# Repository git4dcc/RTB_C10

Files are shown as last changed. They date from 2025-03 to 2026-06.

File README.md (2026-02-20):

# RTB_C10





My homebrew RTB C10 Bus Master connects the PC with the model railway layout via USB. The bus master is responsible for the bus timing and scales from small testing beads to large scale layouts.

<details>
<summary>See also</summary>

- [RTB_C11 - Power](/../../../../git4dcc/RTB_C11)
- [RTB_C12 - Booster](/../../../../git4dcc/RTB_C12)
- [RTB_C13 - Track Sensor](/../../../../git4dcc/RTB_C13)
- [RTB_P15 - Base](/../../../../git4dcc/RTB_P15)

</details>

<details>
<summary>User Guides</summary>

- User Guide - DE
- [User Guide - EN](https://rtb4dcc.de/rtb_user_guide_en/)

</details>

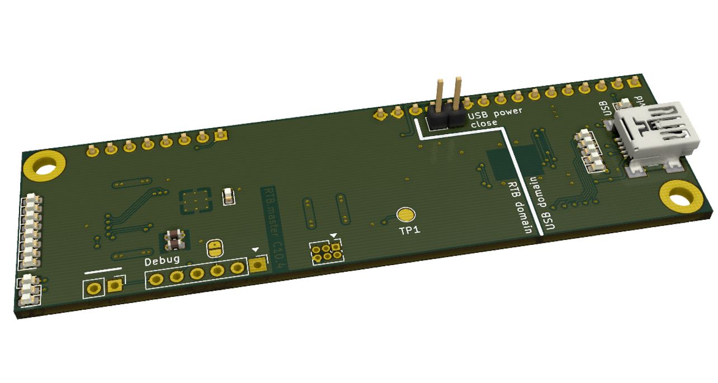
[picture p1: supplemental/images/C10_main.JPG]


## Master features
- **USB**
  - USB 2.0 (3Mbps full duplex)
  - Mini-B connector
  - easy firmware update over USB
  - galvanic isolated
- **USB Power Source**
  - can provide power to other components
  - active limited to 500mA
  - short circuit protection
- **bus master**
  - FDX bus head (2Mbps full duplex)
  - fail safe operation

# Hardware
The PCB layout uses SMD footprints with 0.4mm pitch and postly 0603 parts. Reflow soldering is recommended, but with some experience handsoldering is also possible.
Further, the PCB has been optimized for automated assembly (BOM and Position files as CSV).

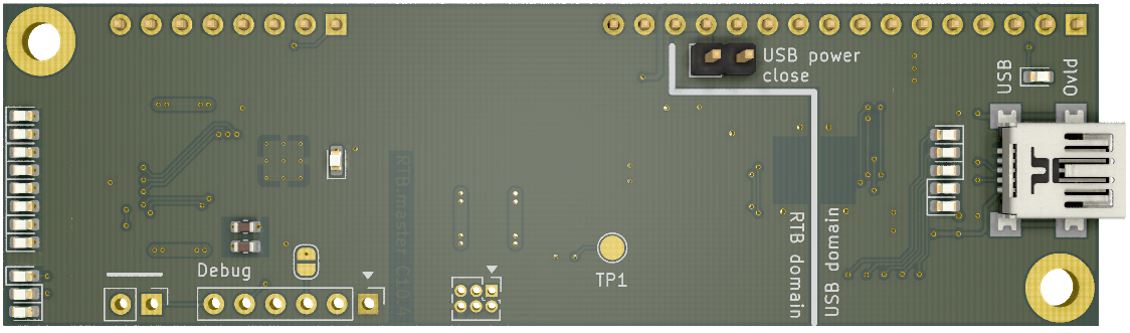
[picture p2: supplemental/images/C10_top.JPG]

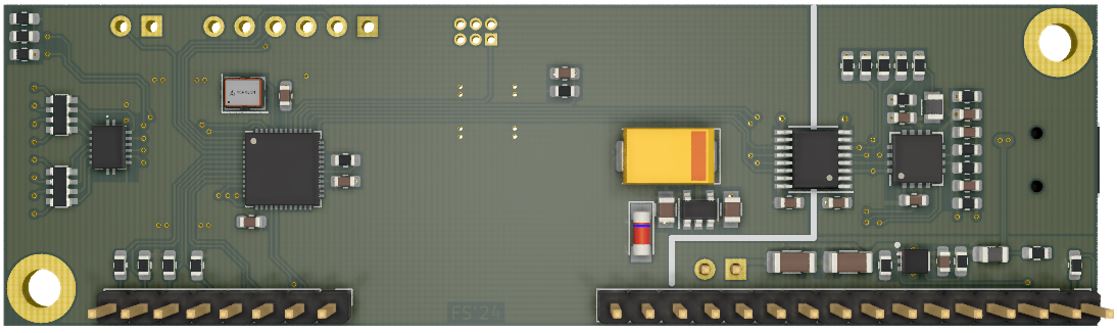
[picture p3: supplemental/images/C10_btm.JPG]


## PCB
- 2-layer PCB, FR4, 1.6mm
- CPU: AVR64DB48
- USB: FT232X (Mini-B)
- PMIC: TPS2552DRVT

## Kicad
[Schematic](doc/C10_schematic.pdf) | [Layout](doc/C10_layout.pdf) | [Gerber](gerber)

<details>
<summary>Dependency</summary>
<br>

:yellow_circle: Requires my Kicad project library [RTB_SamacSys](/../../../../git4dcc/RTB_SamacSys) in the same directory tree.

</details>

## Firmware
Filename structure: { **pcb** }{ **code** }{ **version** }.hex

Example: **C10F0001**.hex

| | Description |
| --- | --- |
| **pcb** | Name of matching hardware (**C10**) |
| **code** | Type of code contained (**R**=rom, **B**=bootloader, **F**=flash, **U**=bld update, **P**=UPDI factory code) |
| **version** | Release version (**####**) |

[Firmware files](firmware)

## UPDI / Fuses
The fuse settings as well as the P-code (C10Pxxxx.hex) has to be installed by using UPDI.<br>

| Fuses Setting |
| --- |
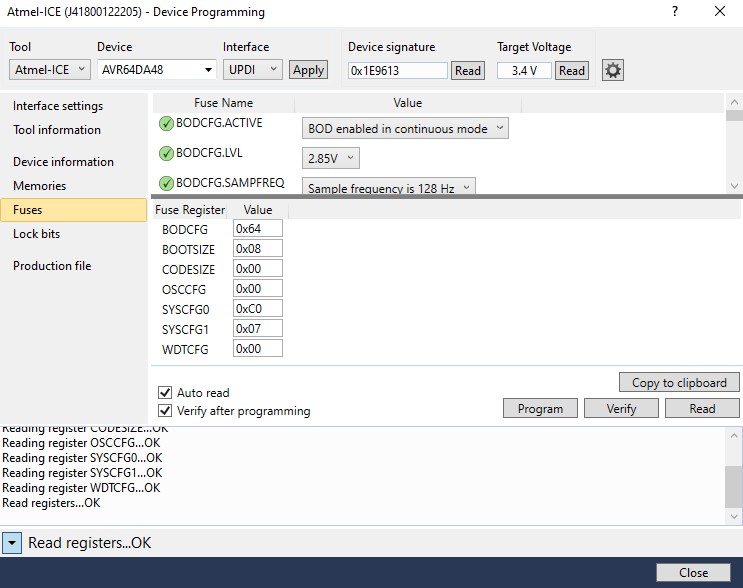
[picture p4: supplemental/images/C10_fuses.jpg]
||

# Images
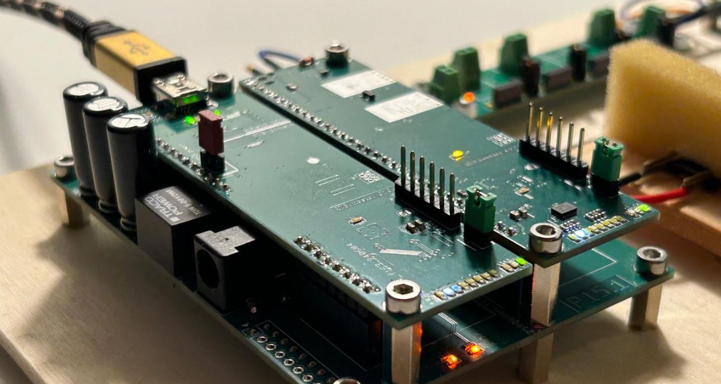
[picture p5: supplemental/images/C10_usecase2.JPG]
 

# YouTube
See the C10 bus master in action.<br><br>
[](https://youtu.be/n1b2I9GNrNY)

This project is intended for hobby use only and is distributed in accordance with the Apache License 2.0 agreement.

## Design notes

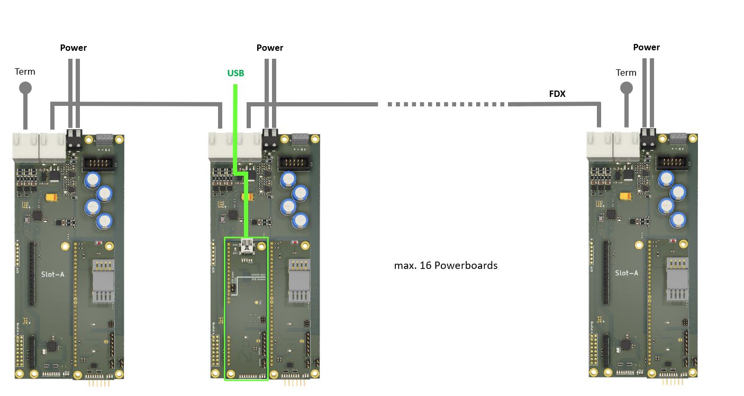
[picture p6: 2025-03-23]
supplemental/images/C10_usecase3.JPG

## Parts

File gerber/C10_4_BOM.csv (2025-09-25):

Designator | Footprint | Quantity | Value | LCSC Part #
C10, C11, C12, C13, C17, C18, C22, C4, C5, C7, C8, C9 | 0603 | 12 | 100nF | C14663
C14, C15 | 0603 | 2 | 47pF | C5137501
C16 | 1206 | 1 | 22uF/25V | C12891
C19, C20 | 1206 | 2 | 220u/6.3V | C15008
C2 | 0805 | 1 | 100nF/50V | C49678
C3 | 0805 | 1 | 10uF/25V | C5137488
C6 | 0603 | 1 | 4.7uF | C19666
D1 | D_SOD-123F | 1 | BAS16H,115 | C130413
D11, D12 | 0603 | 2 | LED(grn)
D14, D32, D33, D34, D35, D36, D37, D38 | 0603 | 8 | LED(wht) | C2290
D17 | 0603 | 1 | RTS(red)
D18 | 0603 | 1 | CTS(red)
D2 | 0603 | 1 | Locate(blue) | C434421
D3 | 0603 | 1 | Reset(red) | C2986060
D4 | 0603 | 1 | Hbt(grn) | C84264
D5 | 0603 | 1 | PWR(grn) | C84264
D6 | 0603 | 1 | Alarm(pink)
D8 | 0603 | 1 | PWR(grn)
H1, H2 | MountingHole_3.2mm_M3_ISO7380_Pad | 2 | MountingHole
IC1 | SON65P200X200X80-7N | 1 | TPS2553DRVT | C2871420
IC3 | 74HC595BQ115 | 1 | 74HC595BQ,115 | C547123
J1 | USB_Micro-B_Reichelt_BWM_SMD | 1 | USB_B_Mini
J2 | PinHeader_1x16_P2.54mm_Vertical | 1 | Conn_01x16_Male
J3 | PinHeader_1x06_P2.54mm_Vertical | 1 | Debug IF
J4 | PinHeader_2x03_P1.27mm_Vertical | 1 | UPDI
J5 | PinHeader_1x08_P2.54mm_Vertical | 1 | Conn_01x08_Male
JP1 | SolderJumper-2_P1.3mm_Open_RoundedPad1.0x1.5mm | 1 | SolderJumper_2_Open
JP2 | PinHeader_1x02_P2.54mm_Vertical | 1 | Jumper_2_Open
JP3 | PinHeader_1x02_P2.54mm_Vertical | 1 | USB power
L1, L2 | 0805 | 2 | Ferrite_Bead | C845118
R1, R12, R6, R7, R8 | 0603 | 5 | 1k | C21190
R10 | 0603 | 1 | 18k | C25810
R11, R2, R28, R4, R5 | 0603 | 5 | 3.3k | C22978
R15, R22, R23, R29, R30 | 0603 | 5 | 3.3k | 0603WAF3301T5E
R16, R20 | 0603 | 2 | 27 | C23345
R3 | 0603 | 1 | 100 | C22775
R9 | 0603 | 1 | 100k | C25803
RN3, RN4 | R_Array_Convex_4x0603 | 2 | 4.7k | C1980
TP1 | TestPoint_Pad_D2.0mm | 1 | TestPoint
U2 | UQFN-48-1EP_6x6mm_P0.4mm_EP4.45x4.45mm_ThermalVias | 1 | AVR64DA48 | C3227372
U5 | SOT-23-5 | 1 | MIC5205-3.3YM5 | C37970
U6 | QFN-16-1EP_4x4mm_P0.65mm_EP2.7x2.7mm | 1 | FT230XQ | C128629
U7 | SSOP-16_3.9x4.9mm_P0.635mm | 1 | ISO7742 | C5216468
X1 | Oscillator_SMD_Abracon_ASE-4Pin_3.2x2.5mm | 1 | ASE-24MHz | C1987527

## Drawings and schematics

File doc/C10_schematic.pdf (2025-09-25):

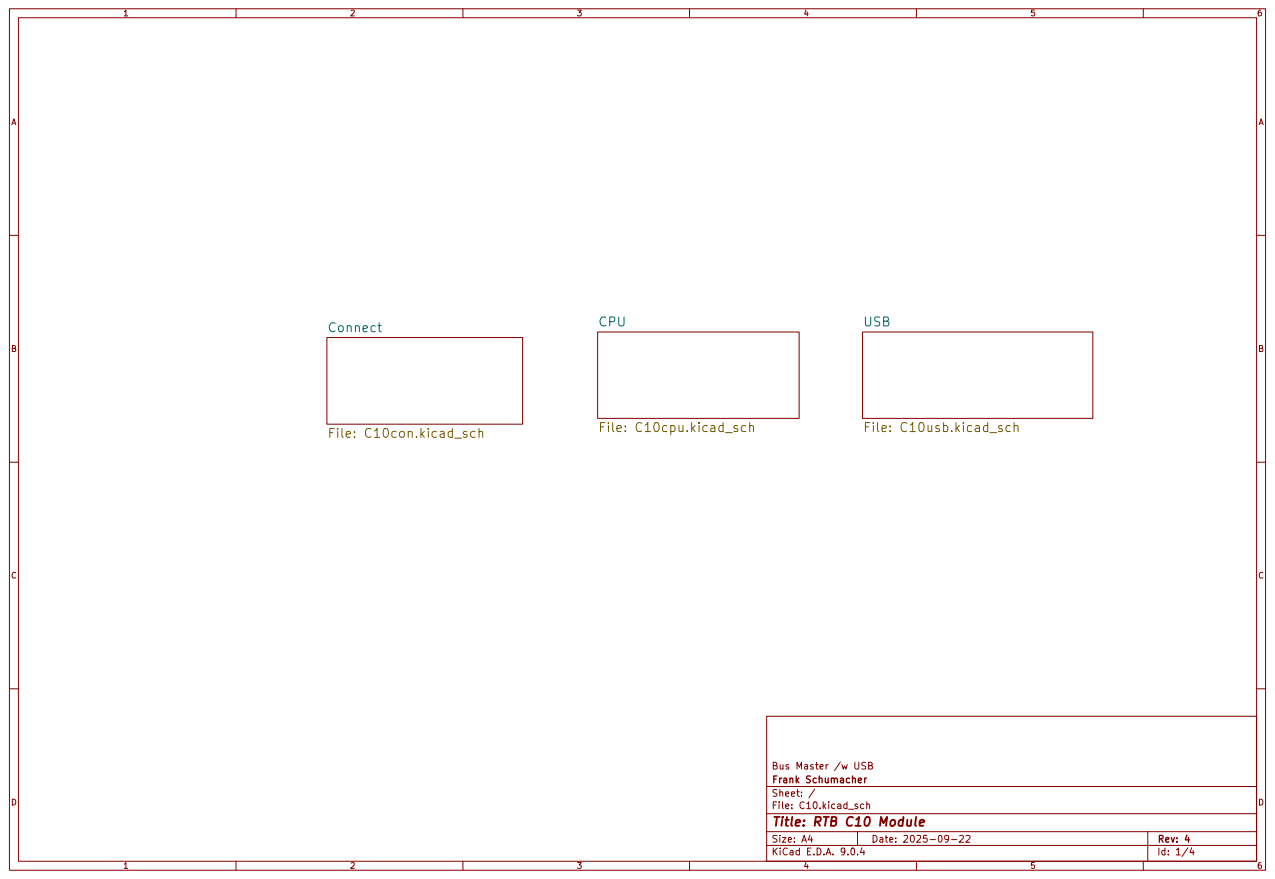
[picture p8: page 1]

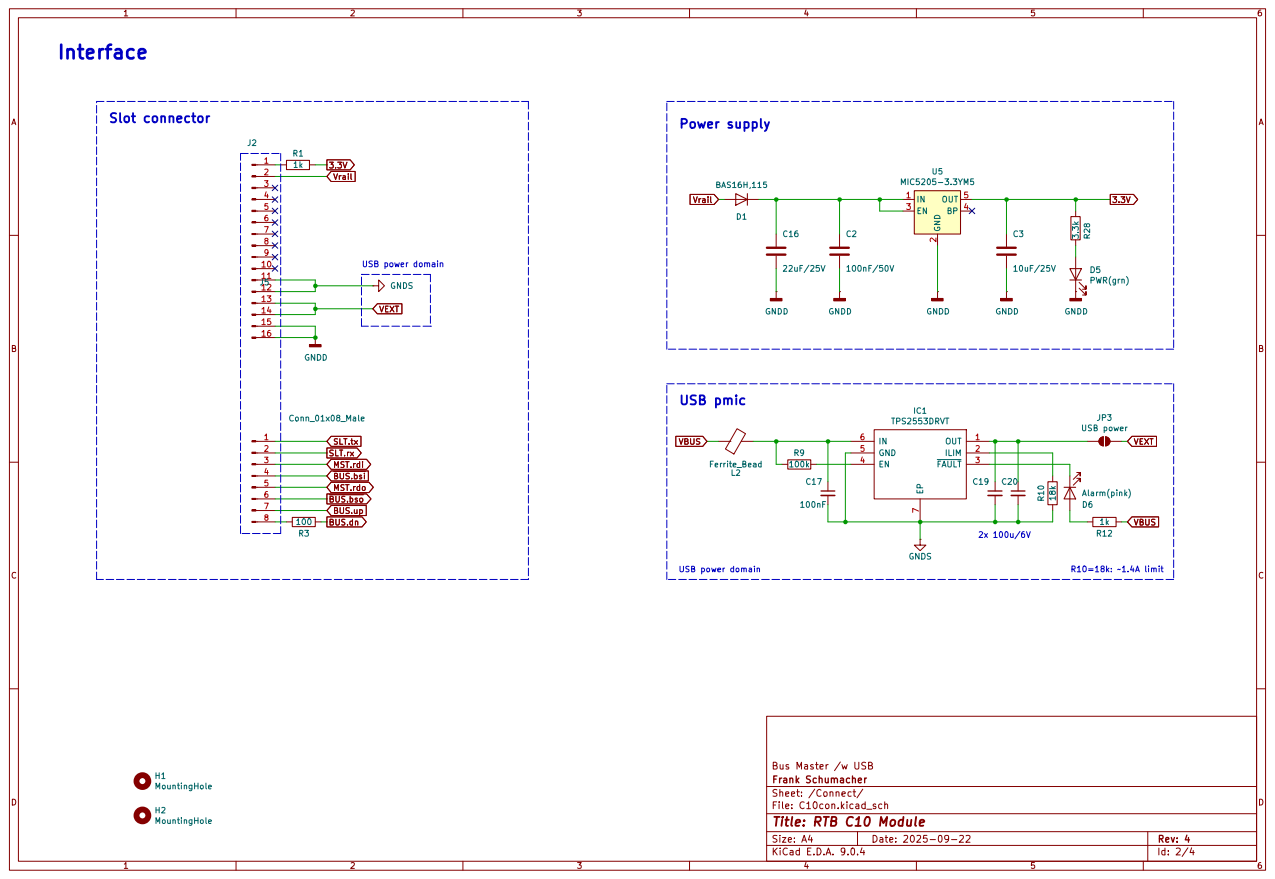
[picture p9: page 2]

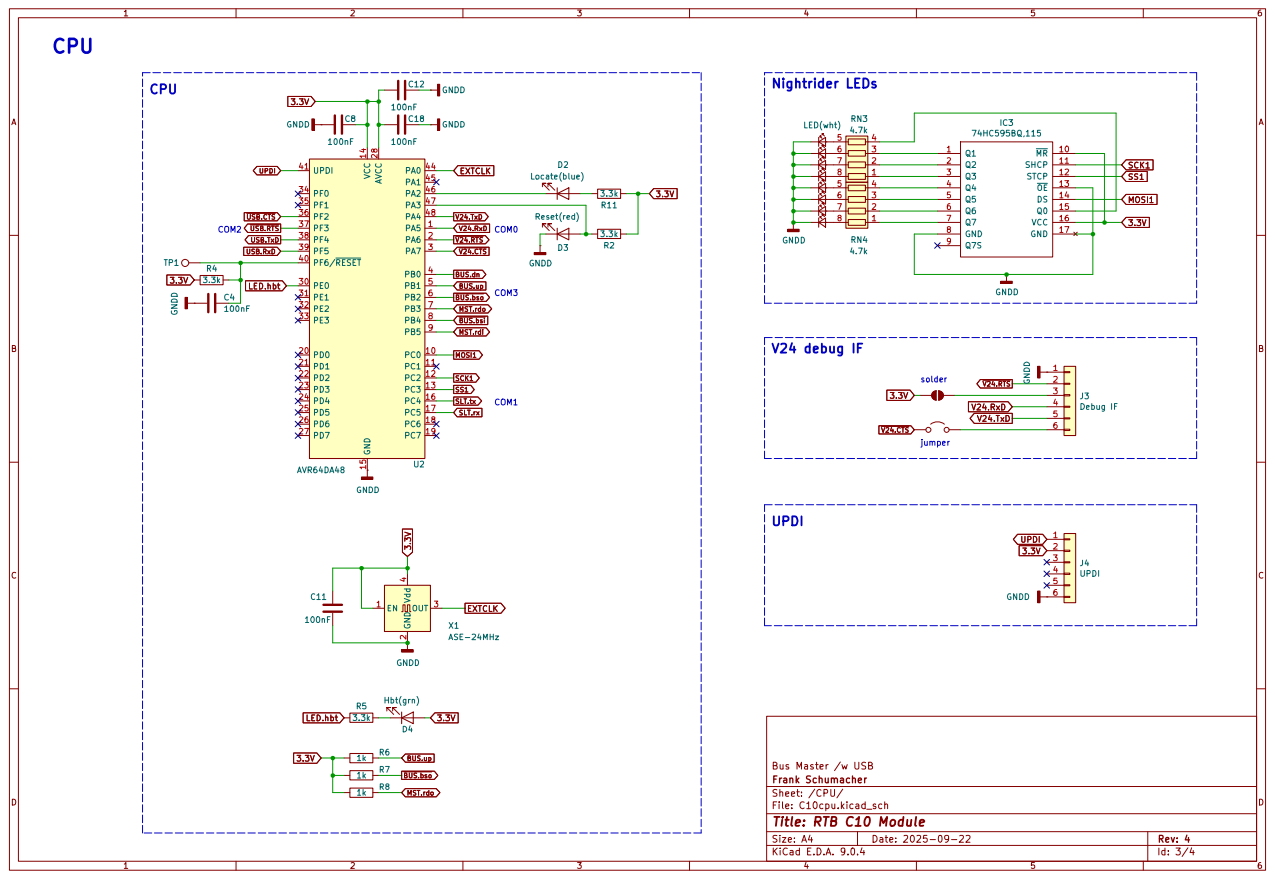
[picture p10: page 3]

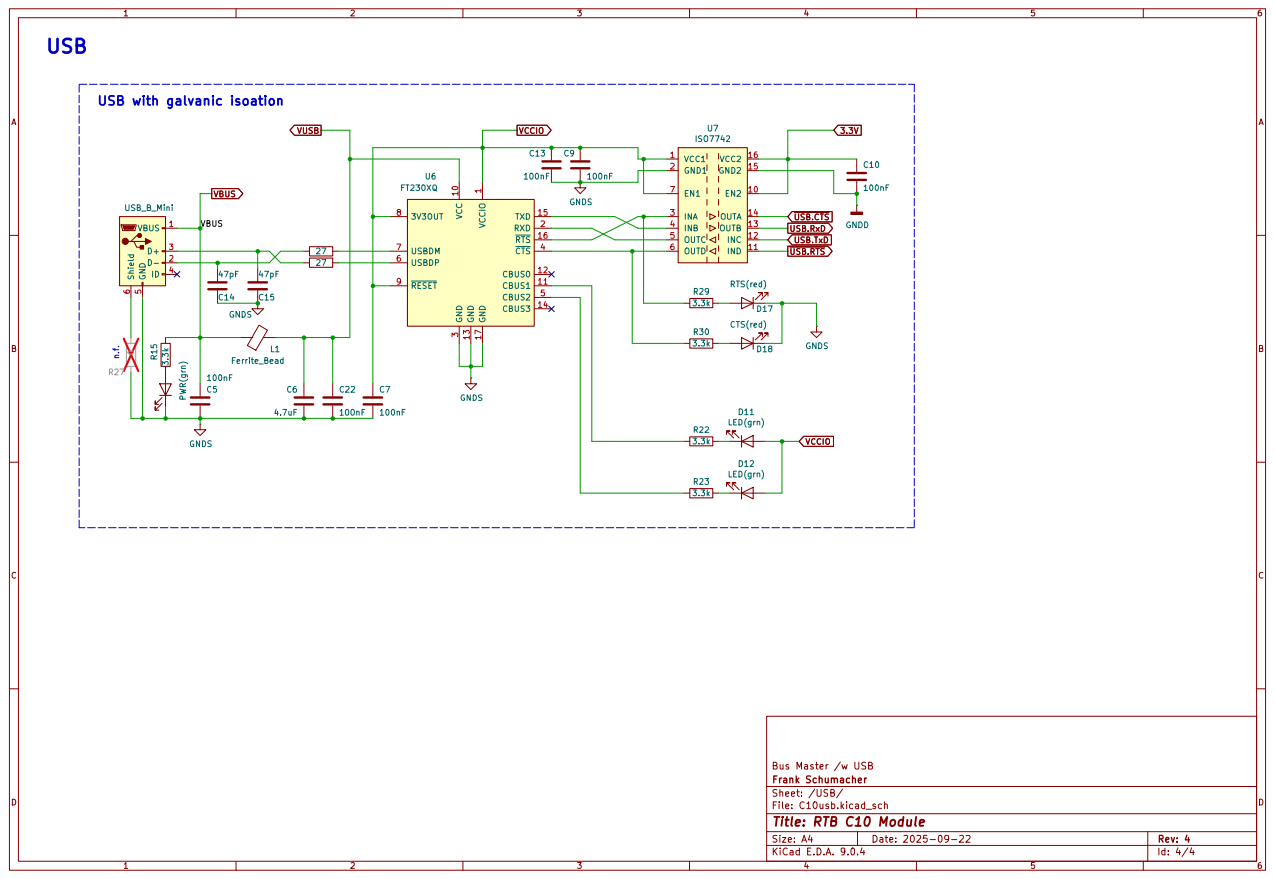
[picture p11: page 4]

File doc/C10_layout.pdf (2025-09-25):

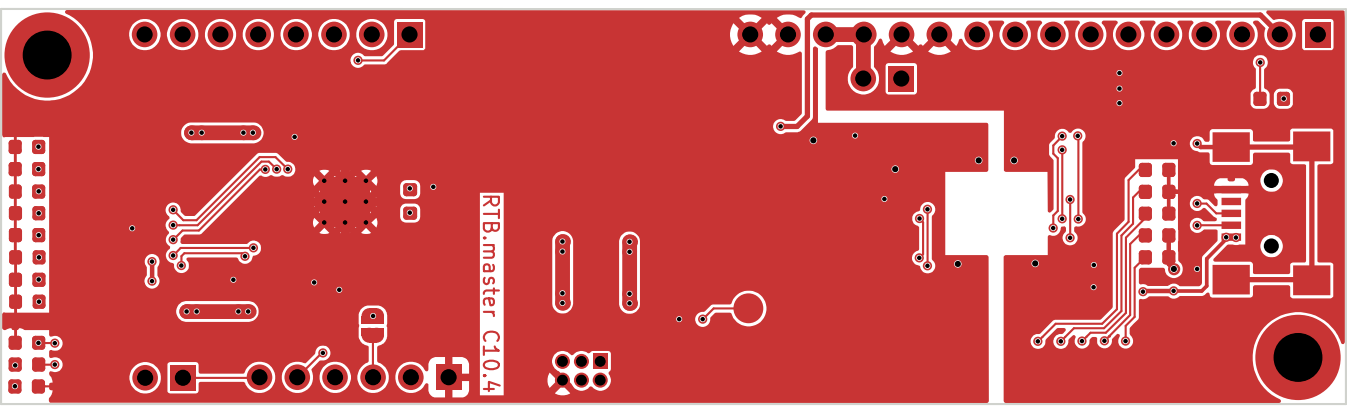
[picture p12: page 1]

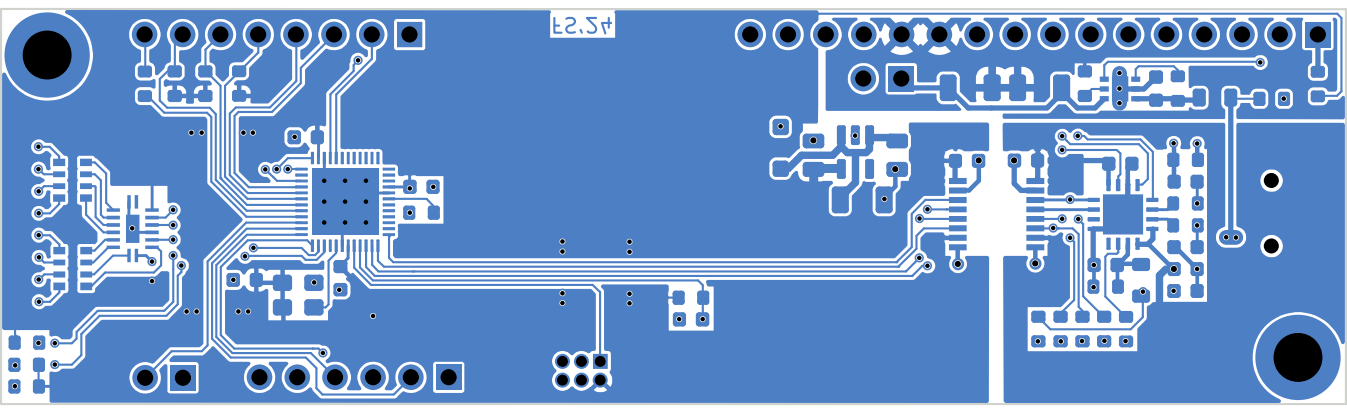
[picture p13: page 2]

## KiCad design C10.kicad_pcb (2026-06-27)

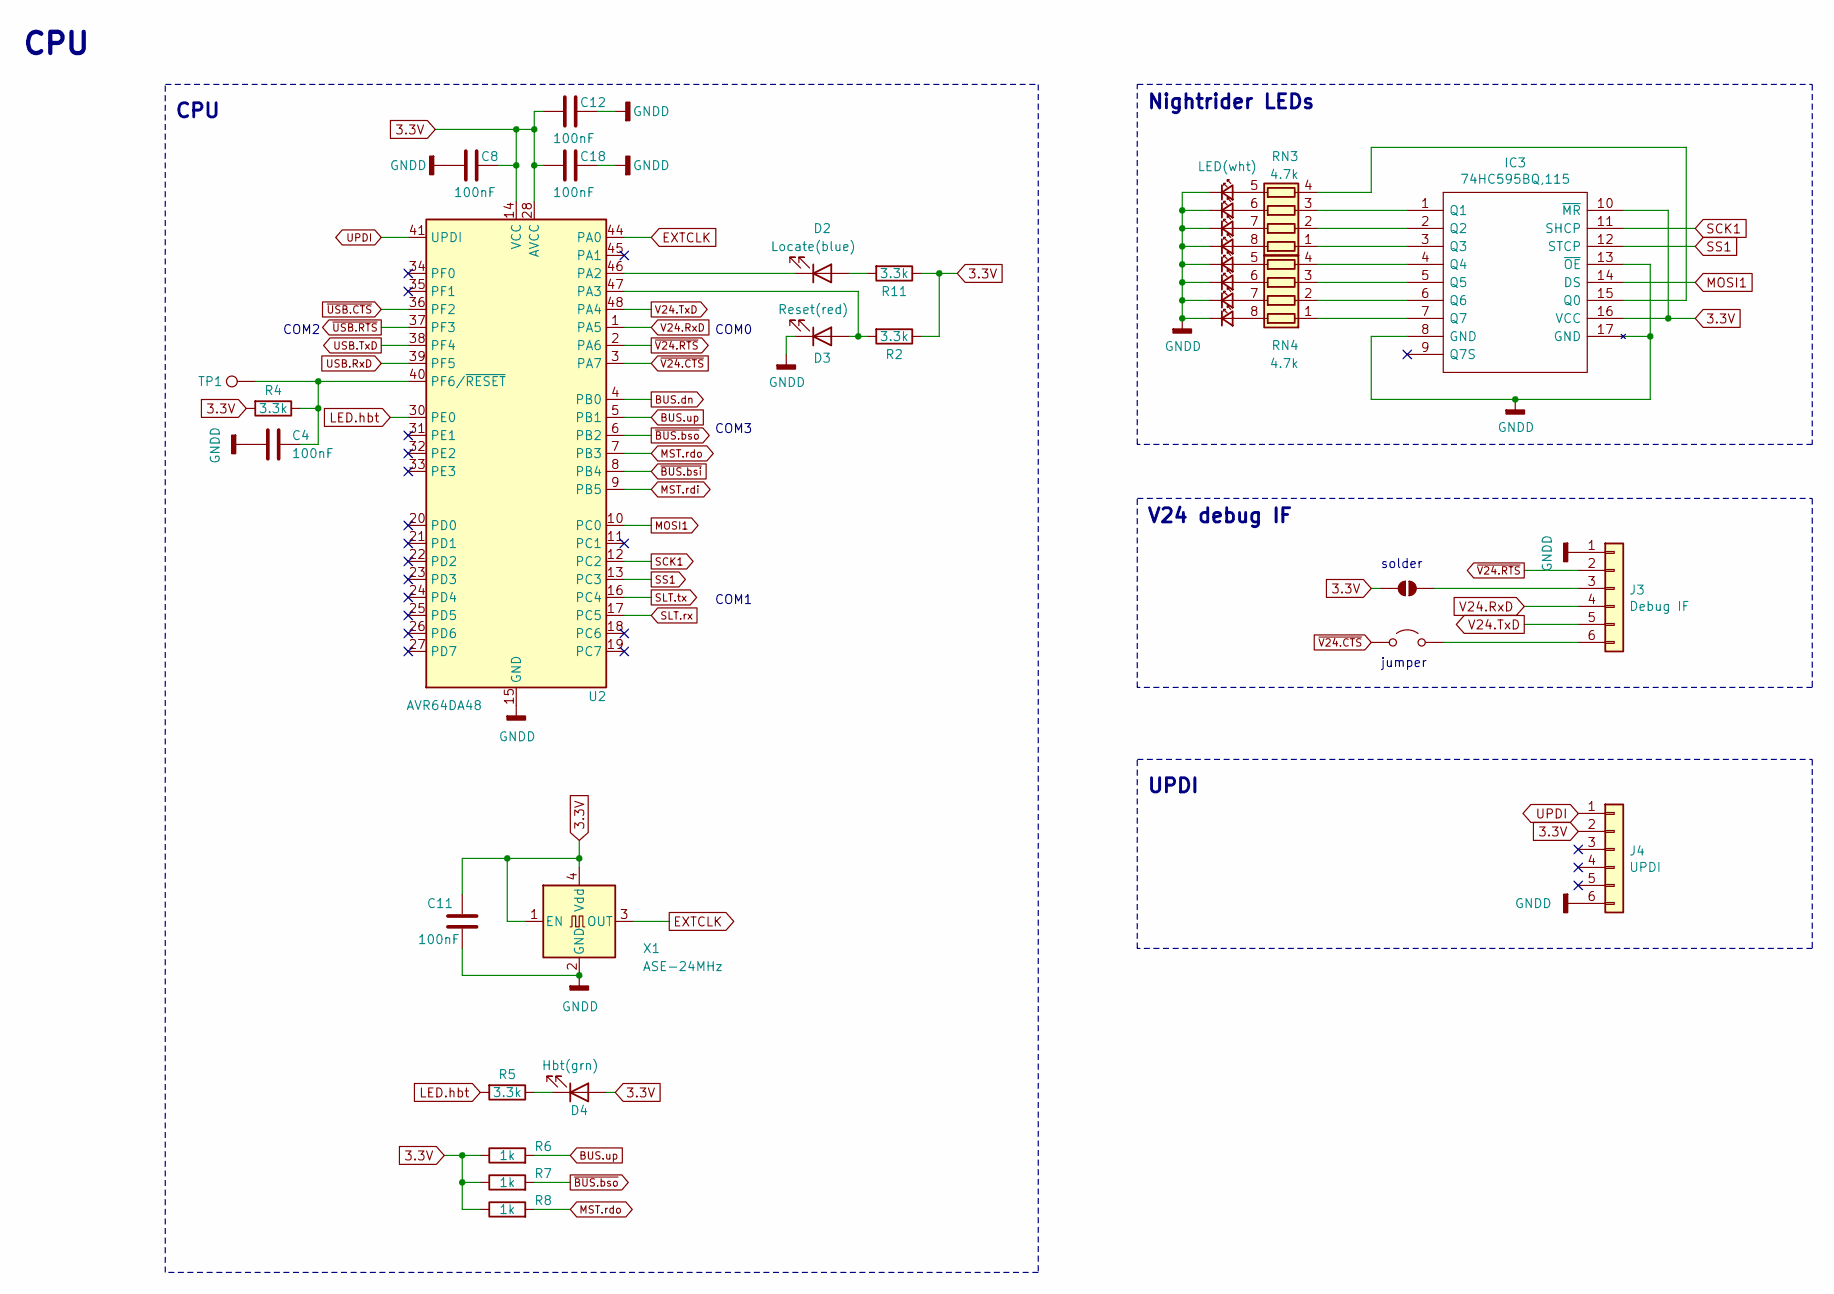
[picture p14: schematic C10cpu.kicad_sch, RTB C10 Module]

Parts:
C4: 100nF; C_0603_1608Metric; LCSC Part # C14663
C8, C12, C18: 100nF; C_0603_1608Metric; Mouser 187-CL10B105KA8NFNC
C11: 100nF; C_0603_1608Metric; Mouser 603-CC603KRX7R9BB104
D2: Locate(blue); LED_0603_1608Metric; LCSC Part # C434421
D3: Reset(red); LED_0603_1608Metric; LCSC Part # C2986060
D4: Hbt(grn); LED_0603_1608Metric; LCSC Part # C84264
D14, D32, D33, D34, D35, D36, D37, D38: LED(wht); LED_0603_1608Metric; LCSC Part # C2290
IC3: 74HC595BQ,115; 74HC595BQ115; LCSC Part # C547123
J3: Debug IF; PinHeader_1x06_P2.54mm_Vertical
J4: UPDI; PinHeader_2x03_P1.27mm_Vertical
JP1: SolderJumper_2_Open; SolderJumper-2_P1.3mm_Open_RoundedPad1.0x1.5mm
JP2: Jumper_2_Open; PinHeader_1x02_P2.54mm_Vertical
R2, R4, R5, R11: 3.3k; R_0603_1608Metric; LCSC Part # C22978
R6, R7, R8: 1k; R_0603_1608Metric; Mouser 603-RC0603FR-101KL
RN3, RN4: 4.7k; R_Array_Convex_4x0603; Mouser 667-EXB-V8V332JV
TP1: TestPoint; TestPoint_Pad_D2.0mm
U2: AVR64DA48; UQFN-48-1EP_6x6mm_P0.4mm_EP4.45x4.45mm_ThermalVias; LCSC Part # C3227372
X1: ASE-24MHz; Oscillator_SMD_Abracon_ASE-4Pin_3.2x2.5mm; LCSC Part # C1987527

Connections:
3.3V: C8.2, C11.1, C12.1, C18.1, D4.2 (A), IC3.10 (~MR), IC3.16 (VCC), J4.2, JP1.1 (A), R2.1, R4.2, R6.1, R7.1, R8.1, R11.1, U2.14 (VCC), U2.28 (AVCC), U2.42 (VCC), X1.1 (EN), X1.4 (Vdd); also elsewhere on the board
BUS.dn: U2.4 (PB0); also elsewhere on the board
BUS.up: R6.2, U2.5 (PB1); also elsewhere on the board
EXTCLK: U2.44 (PA0), X1.3 (OUT)
GNDD: C4.1, C8.1, C11.2, C12.2, C18.2, D3.1 (K), D14.1 (K), D32.1 (K), D33.1 (K), D34.1 (K), D35.1 (K), D36.1 (K), D37.1 (K), D38.1 (K), IC3.8 (GND), IC3.13 (~OE), IC3.17 (GND), J3.1, J4.6, U2.15 (GND), U2.29 (GND), U2.43 (GND), U2.49 (GND), X1.2 (GND); also elsewhere on the board
LED.hbt: R5.2, U2.30 (PE0)
MOSI1: IC3.14 (DS), U2.10 (PC0)
MST.rdi: U2.9 (PB5); also elsewhere on the board
MST.rdo: R8.2, U2.7 (PB3); also elsewhere on the board
unnamed: D2.2 (A), R11.2
unnamed: D2.1 (K), U2.46 (PA2)
unnamed: D3.2 (A), R2.2, U2.47 (PA3)
unnamed: D4.1 (K), R5.1
unnamed: D14.2 (A), RN4.8 (R1.2)
unnamed: D32.2 (A), RN4.7 (R2.2)
unnamed: D33.2 (A), RN4.6 (R3.2)
unnamed: D34.2 (A), RN4.5 (R4.2)
unnamed: D35.2 (A), RN3.8 (R1.2)
unnamed: D36.2 (A), RN3.7 (R2.2)
unnamed: D37.2 (A), RN3.6 (R3.2)
unnamed: D38.2 (A), RN3.5 (R4.2)
unnamed: IC3.15 (Q0), RN3.4 (R4.1)
unnamed: IC3.1 (Q1), RN3.3 (R3.1)
unnamed: IC3.2 (Q2), RN3.2 (R2.1)
unnamed: IC3.3 (Q3), RN3.1 (R1.1)
unnamed: IC3.4 (Q4), RN4.4 (R4.1)
unnamed: IC3.5 (Q5), RN4.3 (R3.1)
unnamed: IC3.6 (Q6), RN4.2 (R2.1)
unnamed: IC3.7 (Q7), RN4.1 (R1.1)
unnamed: J3.3, JP1.2 (B)
unnamed: J3.6, JP2.1 (A)
unnamed: C4.2, R4.1, TP1.1 (1_1), U2.40 (PF6/~RESET)
SCK1: IC3.11 (SHCP), U2.12 (PC2)
SLT.rx: U2.17 (PC5); also elsewhere on the board
SLT.tx: U2.16 (PC4); also elsewhere on the board
SS1: IC3.12 (STCP), U2.13 (PC3)
UPDI: J4.1, U2.41 (UPDI)
USB.RxD: U2.39 (PF5); also elsewhere on the board
USB.TxD: U2.38 (PF4); also elsewhere on the board
V24.RxD: J3.4, U2.1 (PA5)
V24.TxD: J3.5, U2.48 (PA4)
~BUS.bsi: U2.8 (PB4); also elsewhere on the board
~BUS.bso: R7.2, U2.6 (PB2); also elsewhere on the board
~USB.CTS: U2.36 (PF2); also elsewhere on the board
~USB.RTS: U2.37 (PF3); also elsewhere on the board
~V24.CTS: JP2.2 (B), U2.3 (PA7)
~V24.RTS: J3.2, U2.2 (PA6)

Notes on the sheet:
CPU
COM2
jumper
V24 debug IF
COM3
COM1
solder
Nightrider LEDs
COM0
UPDI

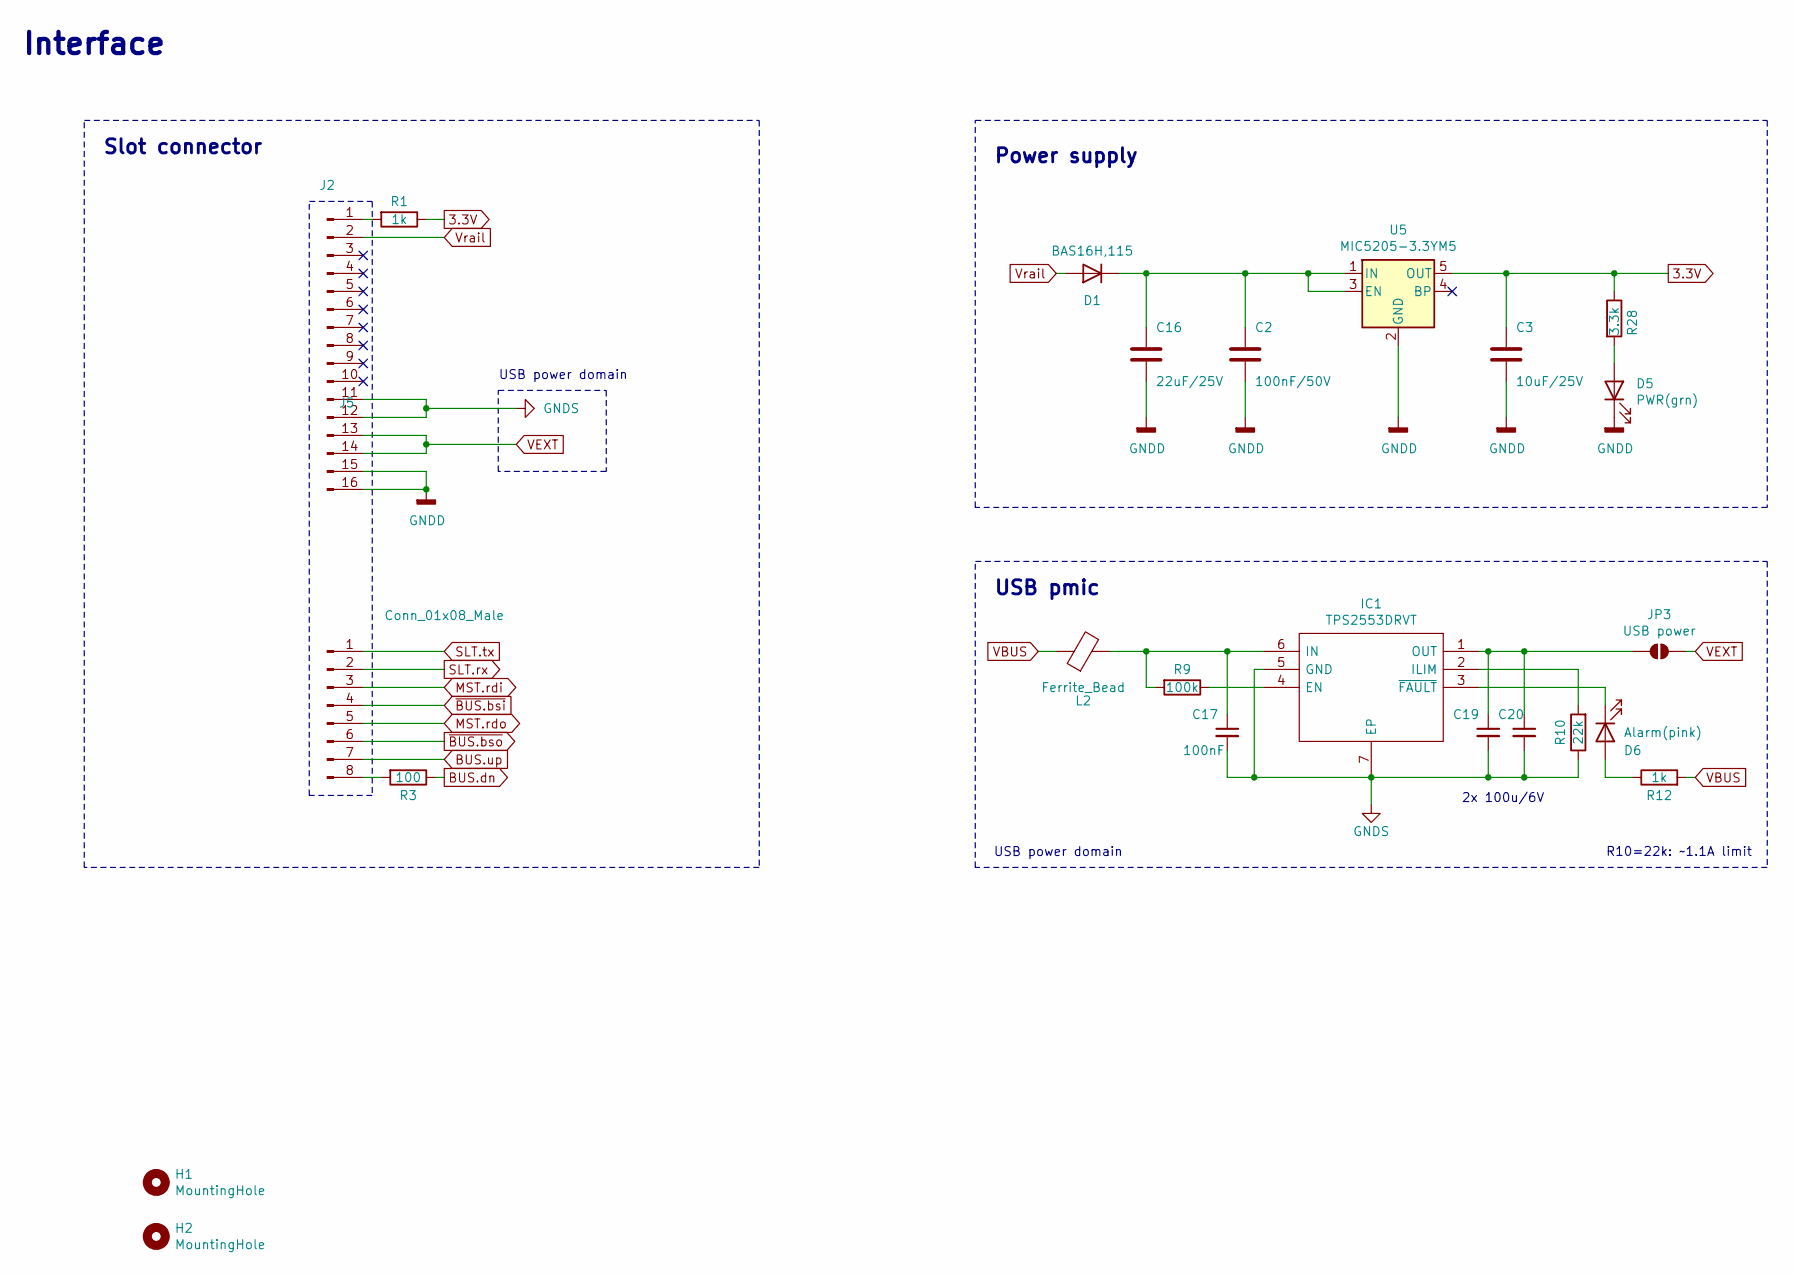
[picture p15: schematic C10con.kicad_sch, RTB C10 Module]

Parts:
C2: 100nF/50V; C_0805_2012Metric; LCSC Part # C49678
C3: 10uF/25V; C_0805_2012Metric; LCSC Part # C5137488
C16: 22uF/25V; C_1206_3216Metric; LCSC Part # C12891
C17: 100nF; C_0603_1608Metric; LCSC Part # C14663
C19, C20: 220u/6.3V; C_1206_3216Metric; LCSC Part # C15008
D1: BAS16H,115; D_SOD-123F; LCSC Part # C130413
D5: PWR(grn); LED_0603_1608Metric; LCSC Part # C84264
D6: Alarm(pink); LED_0603_1608Metric
H1, H2: MountingHole; MountingHole_3.2mm_M3_ISO7380_Pad
IC1: TPS2553DRVT; SON65P200X200X80-7N; LCSC Part # C138719
J2: Conn_01x16_Male; PinHeader_1x16_P2.54mm_Vertical
J5: Conn_01x08_Male; PinHeader_1x08_P2.54mm_Vertical
JP3: USB power; PinHeader_1x02_P2.54mm_Vertical
L2: Ferrite_Bead; L_0805_2012Metric; LCSC Part # C845118
R1, R12: 1k; R_0603_1608Metric; Mouser 603-RC0603FR-101KL
R3: 100; R_0603_1608Metric; Mouser 603-SR0603FR-7T100RL
R9: 100k; R_0603_1608Metric; LCSC Part # C25803
R10: 22k; R_0603_1608Metric; LCSC Part # C31850
R28: 3.3k; R_0603_1608Metric; LCSC Part # C22978
U5: MIC5205-3.3YM5; SOT-23-5; Mouser 998-MIC5205-3.3YM5TR

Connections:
3.3V: C3.1, R1.1, R28.1, U5.5 (OUT); also elsewhere on the board
BUS.dn: R3.1; also elsewhere on the board
BUS.up: J5.7; also elsewhere on the board
GNDD: C2.2, C3.2, C16.2, D5.1 (K), J2.15, J2.16, U5.2 (GND); also elsewhere on the board
GNDS: C17.2, C19.2, C20.2, IC1.5 (GND), IC1.7 (EP), J2.11, J2.12, R10.1; also elsewhere on the board
MST.rdi: J5.3; also elsewhere on the board
MST.rdo: J5.5; also elsewhere on the board
unnamed: C2.1, C16.1, D1.1 (K), U5.1 (IN), U5.3 (EN)
unnamed: D5.2 (A), R28.2
unnamed: D6.2 (A), R12.1
unnamed: D6.1 (K), IC1.3 (~FAULT)
unnamed: IC1.4 (EN), R9.1
unnamed: IC1.2 (ILIM), R10.2
unnamed: C17.1, IC1.6 (IN), L2.2, R9.2
unnamed: C19.1, C20.1, IC1.1 (OUT), JP3.1 (A)
unnamed: J2.1, R1.2
unnamed: J5.8, R3.2
SLT.rx: J5.2; also elsewhere on the board
SLT.tx: J5.1; also elsewhere on the board
VBUS: L2.1, R12.2; also elsewhere on the board
VEXT: J2.13, J2.14, JP3.2 (B)
Vrail: D1.2 (A), J2.2
~BUS.bsi: J5.4; also elsewhere on the board
~BUS.bso: J5.6; also elsewhere on the board

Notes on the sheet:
Slot connector
R10=22k: ~1.1A limit
2x 100u/6V
Interface
USB pmic
Power supply
USB power domain

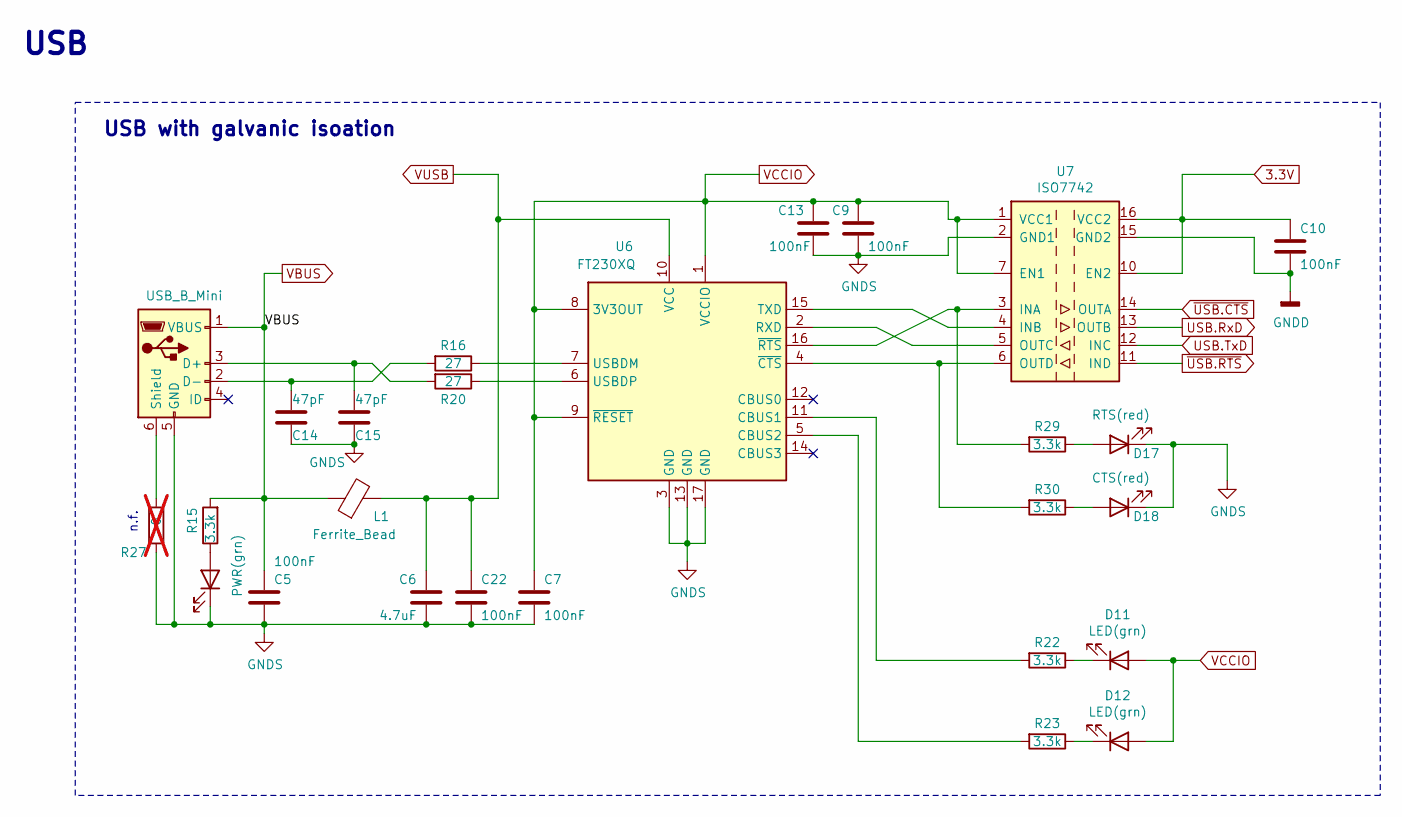
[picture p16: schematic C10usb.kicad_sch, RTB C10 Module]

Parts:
C5, C10, C13, C22: 100nF; C_0603_1608Metric; LCSC Part # C14663
C6: 4.7uF; R_0603_1608Metric; LCSC Part # C19666
C7: 100nF; C_0603_1608Metric; Mouser 963-MAJCU168BB7104KT
C9: 100nF; C_0603_1608Metric; Mouser 187-CL10B105KA8NFNC
C14, C15: 47pF; C_0603_1608Metric; LCSC Part # C5137501
D8: PWR(grn); LED_0603_1608Metric
D11, D12: LED(grn); LED_0603_1608Metric
D17: RTS(red); LED_0603_1608Metric
D18: CTS(red); LED_0603_1608Metric
J1: USB_B_Mini; USB_Micro-B_Reichelt_BWM_SMD; Mouser 649-10033526N3222MLF
L1: Ferrite_Bead; L_0805_2012Metric; Mouser 603-BBPY201209152Y00
R15, R22, R23, R29, R30: 3.3k; R_0603_1608Metric; LCSC Part # 0603WAF3301T5E
R16, R20: 27; R_0603_1608Metric; Mouser 603-RC0603FR-0727RL
R27: 0; R_0603_1608Metric; Mouser 594-MCT0603MZ0000ZP5; not fitted
U6: FT230XQ; QFN-16-1EP_4x4mm_P0.65mm_EP2.7x2.7mm; Mouser 895-FT230XQ-R
U7: ISO7742; SSOP-16_3.9x4.9mm_P0.635mm; Mouser 595-ISO7742QDBQRQ1

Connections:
3.3V: C10.2, U7.10 (EN2), U7.16 (VCC2); also elsewhere on the board
GNDD: C10.1, U7.9 (GND2), U7.15 (GND2); also elsewhere on the board
GNDS: C5.1, C6.2, C7.1, C9.1, C13.1, C14.1, C15.1, C22.1, D8.1 (K), D17.1 (K), D18.1 (K), J1.5 (GND), R27.2, U6.3 (GND), U6.13 (GND), U6.17 (GND), U7.2 (GND1), U7.8 (GND1); also elsewhere on the board
unnamed: D8.2 (A), R15.1
unnamed: D11.1 (K), R22.1
unnamed: D12.1 (K), R23.1
unnamed: D17.2 (A), R29.1
unnamed: D18.2 (A), R30.1
unnamed: C15.2, J1.3 (D+), R20.2
unnamed: C14.2, J1.2 (D-), R16.2
unnamed: J1.6 (Shield), R27.1
unnamed: R22.2, U6.11 (CBUS1)
unnamed: R23.2, U6.5 (CBUS2)
unnamed: U6.2 (RXD), U7.5 (OUTC)
unnamed: U6.15 (TXD), U7.4 (INB)
unnamed: R16.1, U6.7 (USBDM)
unnamed: R20.1, U6.6 (USBDP)
unnamed: R30.2, U6.4 (~CTS), U7.6 (OUTD)
unnamed: R29.2, U6.16 (~RTS), U7.3 (INA)
USB.RxD: U7.13 (OUTB); also elsewhere on the board
USB.TxD: U7.12 (INC); also elsewhere on the board
VBUS: C5.2, J1.1 (VBUS), L1.1, R15.2; also elsewhere on the board
VCCIO: C7.2, C9.2, C13.2, D11.2 (A), D12.2 (A), U6.1 (VCCIO), U6.8 (3V3OUT), U6.9 (~RESET), U7.1 (VCC1), U7.7 (EN1)
VUSB: C6.1, C22.2, L1.2, U6.10 (VCC)
~USB.CTS: U7.14 (OUTA); also elsewhere on the board
~USB.RTS: U7.11 (IND); also elsewhere on the board

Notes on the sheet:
USB
n.f.
USB with galvanic isoation

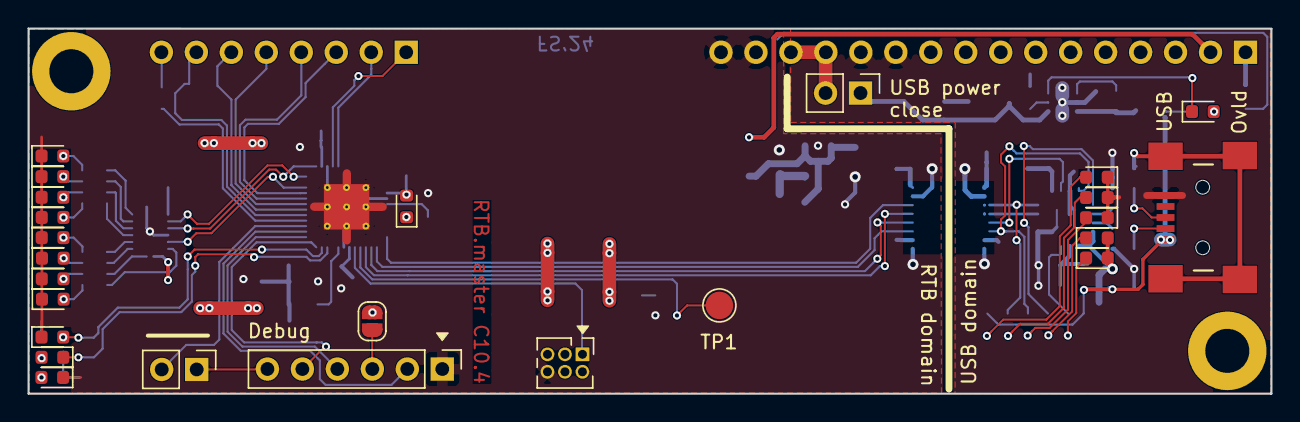
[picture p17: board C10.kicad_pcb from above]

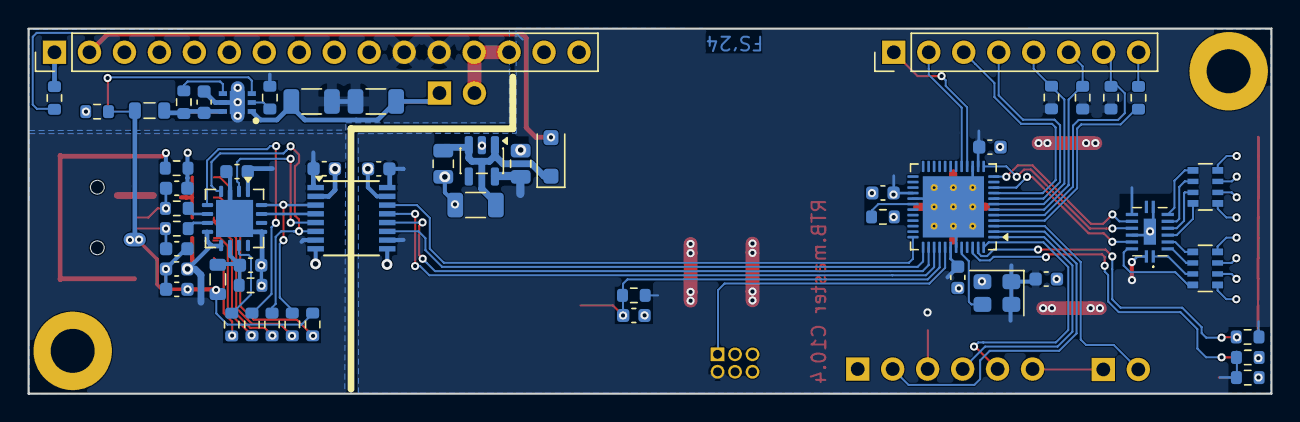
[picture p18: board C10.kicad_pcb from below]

Board: 2 copper layers, 90.3 x 26.5 mm, 82 parts (57 on the bottom side), 79 nets.

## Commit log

2025-03-23 update: documentation
    [C10.kicad_pcb, C10con.sch, C10cpu.sch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]
2025-09-02 mod: optimized for PCB assembly
    [C10.kicad_pcb, C10.sch, C10_4_BOM.xlsx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]
2025-09-25 upgrade to Kicad 9
    [C10.kicad_pcb, C10.kicad_sch, C10_4_BOM.csv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]
2025-11-18 mod: part #
    [C10.kicad_pcb, C10con.kicad_sch, C10cpu.kicad_sch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]
2025-11-18 add: fuses document
2025-11-18 Add UPDI / Fuses section to README
    Added UPDI and fuse settings section to README.
2026-06-27 update: JLCPCB parts
    [C10.kicad_pcb, C10.kicad_sch, C10con.kicad_sch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]
